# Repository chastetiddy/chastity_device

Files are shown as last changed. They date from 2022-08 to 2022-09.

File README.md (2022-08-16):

# chastity_device
Chastity Device: Modification of jfedor's Flatbox R3

This is a modification of [jfedor's flatbox rev3](https://github.com/jfedor2/flatbox/tree/master/hardware-rev3).

I've made some minor rearrangements to the traces and button placement, as well as changing the tact switches to SMD parts. The board itself is a rounded rectangle as well, so as to use a stacked acrylic case.

To fully assemble you will need:

* [Brook PS3/PS4 fighting board PCB](https://www.brookaccessory.com/detail/58690501/)
* 12x Kailh low profile (choc v1) switches of your choice
* Compatible keycaps
* 6x Chicago Screws
* Acrylic panels for the case
* Soldering iron

You will need 1 each of acrylic panels 1-4. They must be the following thicknesses:

* 1 - Bottom Panel: Any
* 2 - Lower Mid Panel: Any
* 3 - Upper Mid Panel: 4.5mm. A thinner panel will not provide enough spacing for the top panel to sit flat above the tact switches.
* 4 - Top Panel: 3 mm. A thicker panel will render the tact switches unusable.

More detailed documentation forthcoming.

PCB design licensed under [CC BY-SA 4.0](https://creativecommons.org/licenses/by-sa/4.0/).

PCB design uses the following libraries:

* [keyswitches.pretty](https://github.com/daprice/keyswitches.pretty) by [daprice](https://github.com/daprice) ([CC BY-SA 4.0](https://creativecommons.org/licenses/by-sa/4.0/))
* [Type-C.pretty](https://github.com/ai03-2725/Type-C.pretty) by [ai03-2725](https://github.com/ai03-2725)

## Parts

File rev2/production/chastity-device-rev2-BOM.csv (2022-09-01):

Comment | Designator | Footprint | LCSC
Brook_PS3PS4_PCBA | A1 | Brook:Brook_PS3PS4_PCBA
5.1k | R1,R2 | SW-SMD_4P-L6.0-W6.0-P4.50-LS9.0-2 | C27834
SW_Push | SW1,SW2,SW3,SW4,SW5,SW6 | Button_Switch_THT:SW_PUSH_6mm_H6mm | C720317
SW_Push | SW7,SW8,SW9,SW10,SW11,SW12,SW13,SW14,SW15,SW16,SW17,SW18 | Kailh:Kailh_socket_PG1350_optional
HRO-TYPE-C-31-M-12 | USB1 | Type-C:HRO-TYPE-C-31-M-12-Assembly | C165948
SW_SLIDE | SW19,SW20 | C&K:PCM12SMTR | C221841

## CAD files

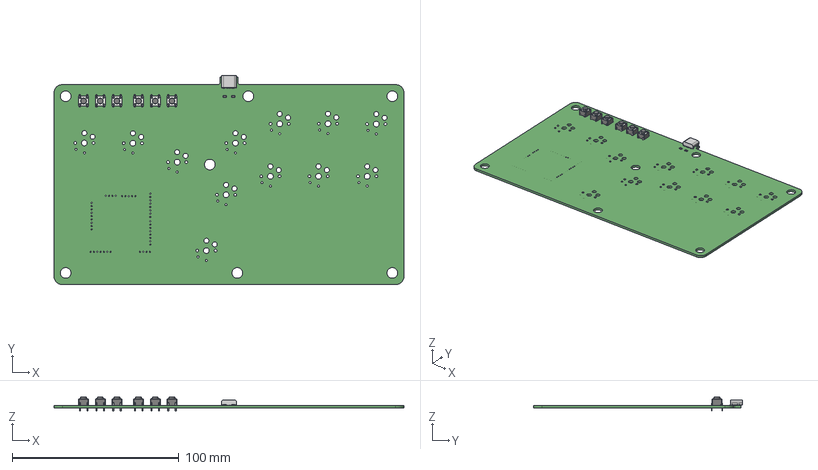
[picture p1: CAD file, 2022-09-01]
rev2/chastity-device-rev2.step
210.0 x 125.5 x 8.50 mm

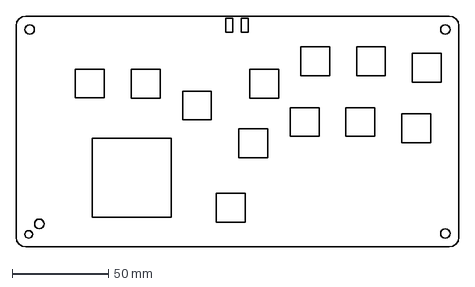
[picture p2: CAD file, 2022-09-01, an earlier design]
rev1/acrylic/2-lower-mid-panel.dxf
230.0 x 120.0 mm

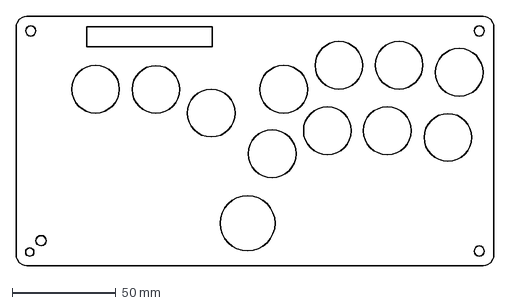
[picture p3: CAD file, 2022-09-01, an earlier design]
rev1/acrylic/4-top-panel.dxf
230.0 x 120.0 mm

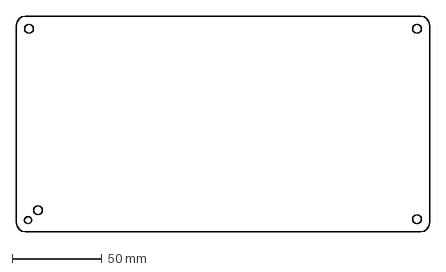
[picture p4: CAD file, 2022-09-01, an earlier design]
rev1/acrylic/1-bottom-panel.dxf
230.0 x 120.0 mm

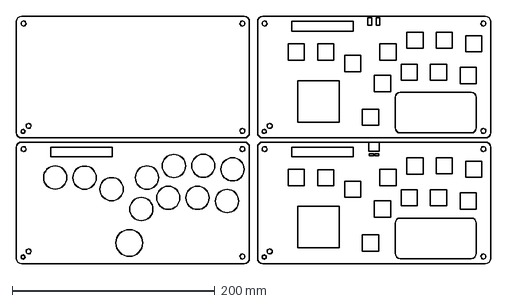
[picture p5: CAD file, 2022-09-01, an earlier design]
rev1/acrylic/chastity-rev-1.dxf
468.0 x 244.0 mm

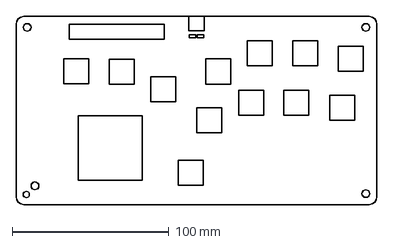
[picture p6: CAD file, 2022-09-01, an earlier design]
rev1/acrylic/3-upper-mid-panel.dxf
230.0 x 120.0 mm

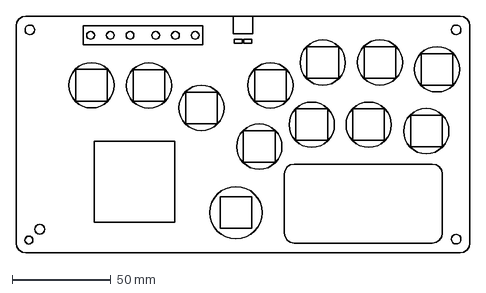
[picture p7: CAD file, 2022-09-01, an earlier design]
rev1/acrylic/0-master-panel-template.dxf
230.0 x 120.0 mm

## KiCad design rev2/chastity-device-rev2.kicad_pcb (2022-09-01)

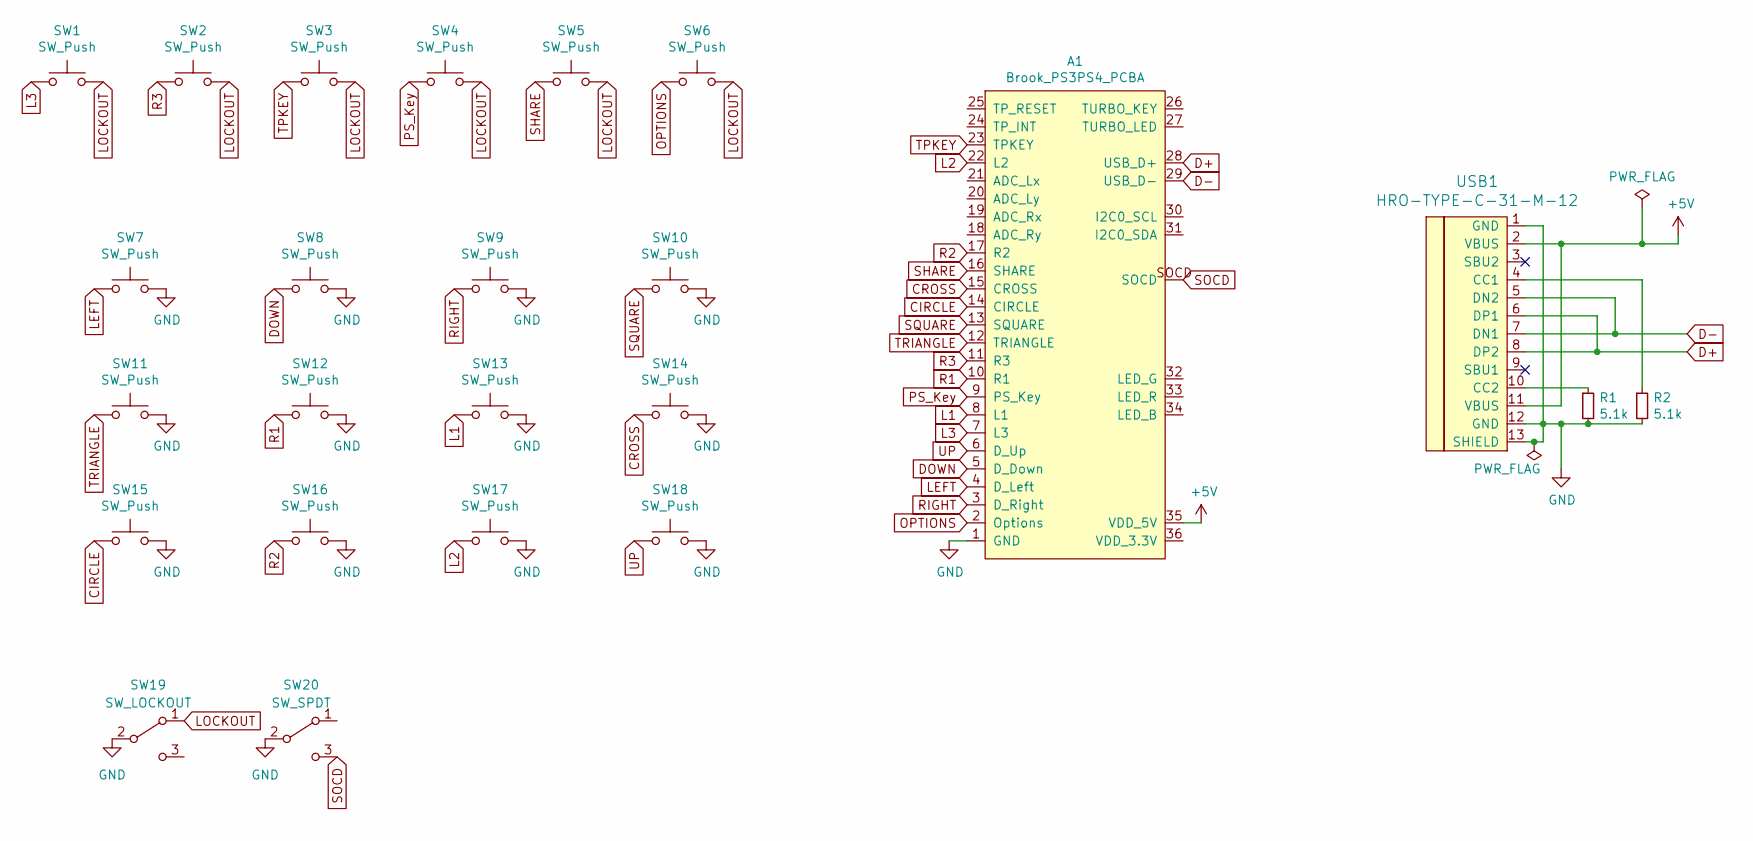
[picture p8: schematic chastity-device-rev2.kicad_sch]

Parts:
A1: Brook_PS3PS4_PCBA
R1, R2: 5.1k; R_0805_2012Metric; LCSC C27834
SW1, SW2, SW3, SW4, SW5, SW6: SW_Push; SW_Push_1P1T_NO_6x6mm_H9.5mm
SW7, SW8, SW9, SW10, SW11, SW12, SW13, SW14, SW15, SW16, SW17, SW18: SW_Push; Kailh_socket_PG1350_optional
SW19: SW_LOCKOUT; SW_SPDT_PCM12
SW20: SW_SPDT; SW_SPDT_PCM12
USB1: HRO-TYPE-C-31-M-12; HRO-TYPE-C-31-M-12-Assembly; LCSC C165948

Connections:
+5V: A1.35 (VDD_5V), USB1.2 (VBUS), USB1.11 (VBUS)
CIRCLE: A1.14 (CIRCLE), SW15.1
CROSS: A1.15 (CROSS), SW14.1
D+: A1.28 (USB_D+), USB1.6 (DP1), USB1.8 (DP2)
D-: A1.29 (USB_D-), USB1.5 (DN2), USB1.7 (DN1)
DOWN: A1.5 (D_Down), SW8.1
GND: A1.1 (GND), R1.2, R2.2, SW7.2, SW8.2, SW9.2, SW10.2, SW11.2, SW12.2, SW13.2, SW14.2, SW15.2, SW16.2, SW17.2, SW18.2, SW19.2 (B), SW20.2 (B), USB1.1 (GND), USB1.12 (GND), USB1.13 (SHIELD)
L1: A1.8 (L1), SW13.1
L2: A1.22 (L2), SW17.1
L3: A1.7 (L3), SW1.1
LEFT: A1.4 (D_Left), SW7.1
LOCKOUT: SW1.2, SW2.2, SW3.2, SW4.2, SW5.2, SW6.2, SW19.1 (A)
unnamed: R1.1, USB1.10 (CC2)
unnamed: R2.1, USB1.4 (CC1)
OPTIONS: A1.2 (Options), SW6.1
PS_Key: A1.9 (PS_Key), SW4.1
R1: A1.10 (R1), SW12.1
R2: A1.17 (R2), SW16.1
R3: A1.11 (R3), SW2.1
RIGHT: A1.3 (D_Right), SW9.1
SHARE: A1.16 (SHARE), SW5.1
SOCD: A1.SOCD, SW20.3 (C)
SQUARE: A1.13 (SQUARE), SW10.1
TPKEY: A1.23 (TPKEY), SW3.1
TRIANGLE: A1.12 (TRIANGLE), SW11.1
UP: A1.6 (D_Up), SW18.1

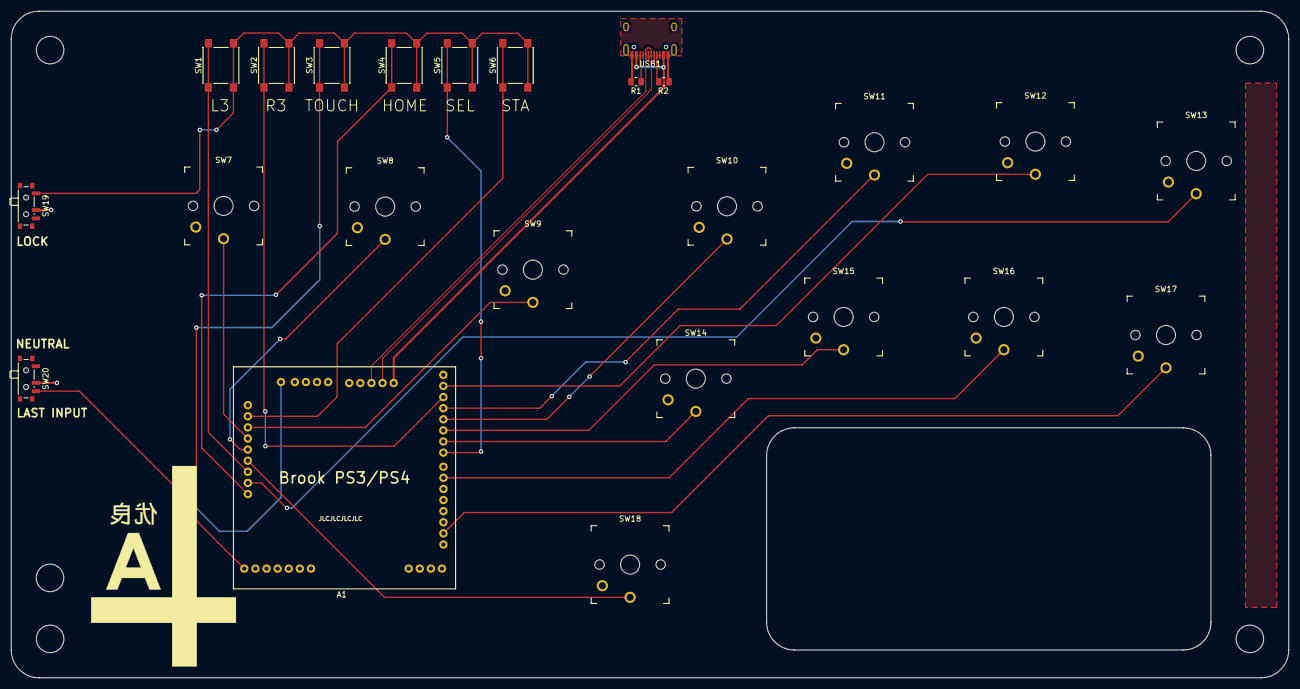
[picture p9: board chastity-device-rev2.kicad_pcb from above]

Board: 2 copper layers, 230.0 x 120.0 mm, 24 parts (0 on the bottom side), 26 nets.

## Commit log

2022-08-16 Rev 1
    [0-master-panel-template.dxf, 1-bottom-panel.dxf, 2-lower-mid-panel.dxf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]
2022-09-01 Updated Rev1 and added Rev2
    Reorganized folder structure.
    Added Rev1.1 redesign with ground pour and different hole placement. Acrylic design for 1.1 TBD.
    Added Rev2 with SOCD and lockout switches. Acrylic design for Rev2 TBD.
    [0-master-panel-template.dxf, 1-bottom-panel.dxf, 2-lower-mid-panel.dxf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]
